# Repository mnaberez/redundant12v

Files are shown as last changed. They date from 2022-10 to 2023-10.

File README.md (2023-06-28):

# Rackmount Redundant 12V Power Supply

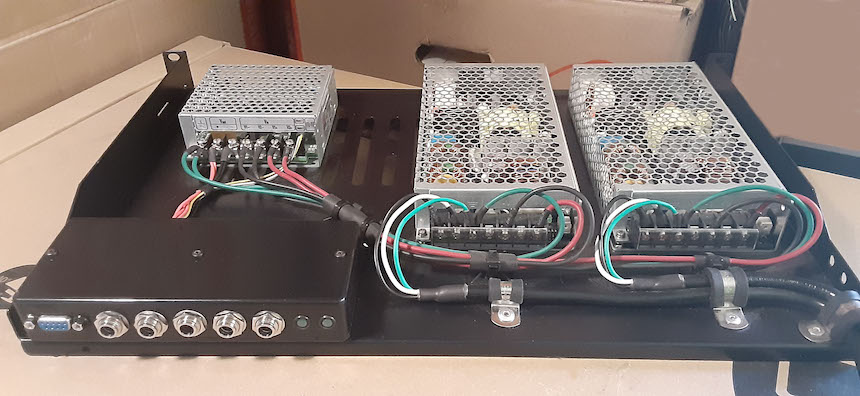
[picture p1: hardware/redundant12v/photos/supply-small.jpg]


This is a redundant, but not hot-swappable, 12VDC power supply.  It has these features:

 - Two AC cords.  Either cord can lose AC power without disrupting the 12VDC output.

 - Five 12VDC output jacks.  Any individual jack can supply ~6A maximum but the supply is only capable of providing ~16A maximum across all jacks.

 - Remote monitoring.  A serial port provides a simple "on/off" status that indicates when one of the two onboard DC supplies loses its AC power or otherwise fails.

It is built on a 1U rack shelf but requires at least 2U because it is slightly taller than 1U.  The extra air space is also needed for cooling because the supply has no fans.

## Background

Rackmount [Automatic Transfer Switches](https://web.archive.org/web/20220408134749/https://www.youtube.com/watch?v=JSWmmY9tKrM) from companies such as [APC](https://web.archive.org/web/20220408135631if_/https://download.schneider-electric.com/files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) and [CyberPower](https://web.archive.org/web/20220408140138if_/https://www.cyberpower.com/tw/en/File/GetCyberpowerFileByDocId/DS-21040002-01) can be used to provide AC power redundancy for devices with a single AC cord.  I wanted redundant power for the single-corded devices in my rack and noticed that they all ran off 12VDC power bricks.  Instead of buying an ATS unit and plugging the bricks into it, I built this redundant 12VDC supply to eliminate the bricks.  It can be built for less than the cost of most ATS units.

## Parts List

| Part | Qty | Notes |
|---|-----|---|
|[Meanwell ERDN40-12 12VDC Redundancy Module](https://www.mouser.com/ProductDetail/709-ERDN40-12) | 1 | [Datasheet](https://web.archive.org/web/20220407021145if_/https://www.meanwell.com/upload/pdf/ERDN40/ERDN40-spec.pdf) |
|[Meanwell MSP-200-12 12VDC 16.7A Power Supply](https://www.mouser.com/ProductDetail/709-MSP200-12) | 2 | [Datasheet](https://web.archive.org/web/20220407021309if_/https://www.mouser.com/datasheet/2/260/MSP_200_SPEC-1109886.pdf).  Selected for built-in protections and no required minimum current. |
|[Pinfox 10' 18 AWG 3 Prong Heavy Duty 120V 10A AC Cord](https://www.amazon.com/gp/product/B07QYRMD6D) | 2 | One AC cord for each MSP-200-12. |
|[Raising Electronics 701401004 19" 1U 12" Deep Rack Shelf](https://www.amazon.com/gp/product/B01M8HKRA7) | 1 | [Product Page](https://web.archive.org/web/20220408132026if_/https://risingracks.com/cantilever-server-shelf-vented-black-shelves-rack-mount-19-1u-12-300mm-deep/) |
|[10pc M3x6mm Plastic Pan Head Screw](https://www.ebay.com/itm/254913074827) | 1 | 10 screws used for mounting the Meanwell units to the shelf.  Plastic ensures no possibility of shorting. |
|[10pc M3x25mm Female-Female Steel Standoff](https://www.ebay.com/itm/113410581076) | 1 | 4 standoffs used inside the project box to mount it to the shelf and secure the lid |
|[25pc M3x8mm Pan Head Screw Steel Black](https://www.ebay.com/itm/111839544046) | 1 | 8 screws used with the 4 project box standoffs (2 screws per standoff) |
|[50pcs M3x6mm Nylon Standoffs with M3x6mm Nylon Screws](https://www.ebay.com/itm/262850128455) | 1 | 4 standoffs and 4 screws used to mount PCB inside project box.  Plastic ensures no possibility of shorting.  Standoffs are epoxied to the project box. |
|[Hammond 1591HSBK Project Box](https://www.digikey.com/en/products/detail/hammond-manufacturing/1591HSBK/130882) | 1 | [Datasheet](https://web.archive.org/web/20210928162934if_/http://www.hammondmfg.com/pdf/1591H.pdf), [Bulletin](https://web.archive.org/web/20220407164638if_/https://www.mouser.com/datasheet/2/177/1591-1389824.pdf) |
|[L-Com SDG400XS D-Sub 50pc Jackscrew/Washer/Nut](https://www.newark.com/l-com/sdg400xs/jack-screw-4-40-10-16mm/dp/63K2685) | 1 | [Datasheet](https://web.archive.org/web/20220827230745if_/https://www.l-com.com/Images/Downloadables/2D/SDG450XS_2D.pdf).  2 jackscrews, 2 lock washers, and 2 hex nuts used to mount DB9 to project box. |
|[5pcs DB9 Female to IDC Panel Mount](https://www.ebay.com/itm/311374355272) | 1 | 1 DB9 connector used to make the DB9-to-PCB cable inside the project box. |
|[10pcs 2x5 pin IDC Female](https://www.ebay.com/itm/323745402692) | 1 | 1 IDC connector used to make the DB9-to-PCB cable inside the project box.  The top of the strain relief must be shaved down a bit to fit in the box. |
|[Ribbon Cable 14 conductor 6' long](https://www.ebay.com/itm/282211468932) | 1 | Cut down to 10 conductors and 6" long, used to make the DB9-to-PCB cable inside the project box. |
|[DB9 Male/Female 5' Cable](https://www.mouser.com/ProductDetail/523-CS-DSDMDB09MF005) | 1 | [Datasheet](https://web.archive.org/web/20220719155819if_/https://www.mouser.com/datasheet/2/18/1/CS_DSDMDB09MF-2079775.pdf).  For direct connection between the box and a PC with a DB9 serial port. |
|[FTDI-US232R-100 1m USB-Serial Cable](https://www.mouser.com/ProductDetail/895-US232R-100-BLK) | 1 | [Datasheet](https://web.archive.org/web/20220828230546if_/https://www.mouser.com/datasheet/2/163/DS_US232R-10_R-100-500-1669828.pdf).  For connecting to a PC without a DB9 serial port, use this adapter together with the above DB9 cable. |
|[Lumex SSI-LXH387GD Panel Mount Green LED](https://www.mouser.com/ProductDetail/696-SSI-LXH387GD) | 2 | [Datasheet](https://web.archive.org/web/20221002231549if_/https://www.mouser.com/datasheet/2/244/LUMX_S_A0001762456_1-2551886.pdf).  Mounted on project box to show the "on" status of each power supply.
|[Switchcraft L712ASH 2.5mm Locking Barrel Socket](https://www.mouser.com/ProductDetail/502-L712ASH) | 5 | [Datasheet](https://web.archive.org/web/20220407035419if_/https://www.mouser.com/datasheet/2/393/L712ASH-L722ASH_CD-1110860.pdf), [Bulletin](https://web.archive.org/web/20220407164041if_/https://www.switchcraft.com/Documents/switchcraft_npb_637_high_temp_jacks_plugs.pdf).  Mounted on project box for DC outputs. |
|[Switchcraft 761KSH15 2.5mm Locking Barrel Plug](https://www.mouser.com/ProductDetail/502-761KSH15) | 5 | [Datasheet](https://web.archive.org/web/20220407035117if_/https://www.mouser.com/datasheet/2/393/761KSH-S761KSH_CD-1110850.pdf). See bulletin above for electrical info.  For building DC cables out to devices. |
|[14 AWG GXL Wire 10' Long](https://www.ebay.com/itm/293094627307) | 3 | 1 each: red, green, black.  Cut to length for high current DC wiring |
|[1200Pcs Assorted Crimp Terminals](https://www.ebay.com/itm/172856488315) | 1 | 21 M4 size ring connectors used with terminal blocks on Meanwell units |
|[DC Extension Cable 18 AWG 12VDC 10A 33' Long](https://www.ebay.com/itm/133233779533) | 1 | Connectors cut off and discarded; used to make output cables and for wiring inside Project Box |
|[10pc Dupont 2x2 Female Housing](https://www.ebay.com/itm/141510327734) | 1 | 1 housing used to make ERDN40 alarm cable |
|[10pc Dupont 2-pin 26AWG Female-Female Jumper Cable](https://www.ebay.com/itm/254959908608) | 1 | 2 cables used to make ERDN40 alarm cable |
|[Molex KK 22-01-3077 7-pin Housing](https://www.mouser.com/ProductDetail/538-22-01-3077)| 1 | 1 housing used for PCB connector |
|[125pc Rubber Grommet Set](https://www.ebay.com/itm/221291687081) | 1 | 1 grommet used around wiring from ERDN40 into project box |
|[TICONN 80pc Stainless Steel Hose Clamp Set](https://www.amazon.com/gp/product/B094YP2F3D) | 1 | 3 hose clamps used for AC cord strain relief |
|[100pc 1/4" Aluminum Pop Rivet Set](https://www.harborfreight.com/100-piece-1-4-quarter-inch-aluminum-blind-rivet-set-67619.html) | 1 | 3 pop rivets used to secure hose clamps to shelf |
|[6pc Phoenix Contact Cable Tie Mount Base](https://www.mouser.com/ProductDetail/651-3240709) | 1 | 3 bases used for cable management |
|[Panduit Cable Tie Assortment](https://www.mouser.com/ProductDetail/644-KB-550) | 1 | 3 ties used for cable management |
|[42pc Marine Heat Shrink Tubing](https://www.harborfreight.com/42-piece-marine-heat-shrink-tubing-67598.html) | 1 | For insulating cable ends and also cable management |

## PCB Components

| Part | Qty | Reference Designators |
|---|-----|---|
|[ATTINY212-SSF](https://www.mouser.com/ProductDetail/579-ATTINY212-SSF) Microcontroller SOIC-8 | 1 | U1 |
|[MAX232EID](https://www.mouser.com/ProductDetail/595-MAX232EID) TI RS232 Transceiver SOIC-8 | 1 | U2 |
|[ECS-3951M-018-AU-TR](https://www.mouser.com/ProductDetail/520-3951M-018-AU) Oscillator 1.8432 MHz | 1 | X1 |
|[BZX84-A15,215](https://www.mouser.com/ProductDetail/771-BZX84-A15,215) Zener Diode 15V | 1 | D1 |
|[F1206B1R00FSTR](https://www.mouser.com/ProductDetail/581-F1206B1R00FSTR) Fuse 1206 | 1 | F1 |
|[08055C104J4T2A](https://www.mouser.com/ProductDetail/581-08055C104J4T2A) Capacitor 0.1uF 50V 0805 | 4 | C1, C2, C4, C8 |
|[08053C105K4Z4A](https://www.mouser.com/ProductDetail/581-08053C105K4Z4A) Capacitor 1uF 25V 0805 | 4 | C3, C5, C6, C7 |
|[CGA4J1X7S1E106K125AC](https://www.mouser.com/ProductDetail/810-CGA4J1X7S1E106K1) Capacitor 10uF 25V 0805 | 1 | C9 |
|[RK73H2ARTTD4702F](https://www.mouser.com/ProductDetail/660-RK73H2ARTTD4702F) Resistor 47K 0805 | 2 | R1, R2 |
|[ERJ-P06F2000V](https://www.mouser.com/ProductDetail/667-ERJ-P06F2000V) Resistor 200ohm  0805 | 2 | R3, R4 |
|[22-12-2074](https://www.mouser.com/ProductDetail/538-22-12-2074) Molex KK 7-pin Right Angle | 1 | J1 |
|[IDC 2x5 Header](https://www.ebay.com/itm/254517739367) Shrouded Through Hole | 1 | J2 |

## Author

[Mike Naberezny](https://github.com/mnaberez)

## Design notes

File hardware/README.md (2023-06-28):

# Hardware

The redundant power supply is mostly wired by hand but a printed circuit board with a microcontroller is used to report the status to a PC.  The board was designed using KiCad.  The [schematic](./redundant12v/schematic.pdf) and [Gerber files](./redundant12v/gerbers.zip) are the final version.  See [`firmware/`](../firmware) for how to program the microcontroller.

## Photos



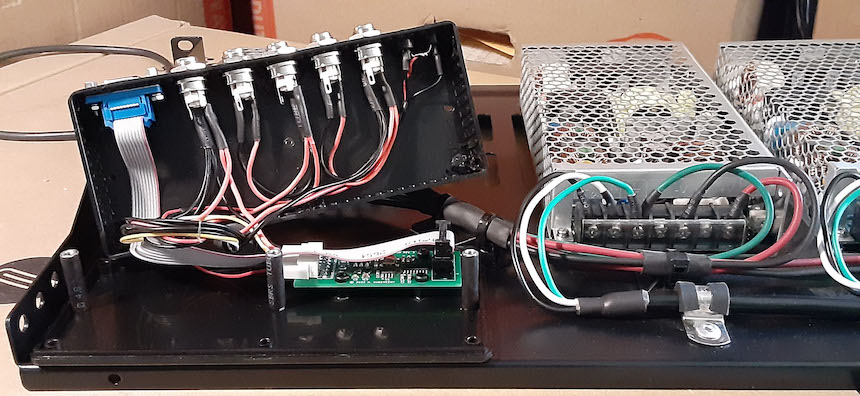
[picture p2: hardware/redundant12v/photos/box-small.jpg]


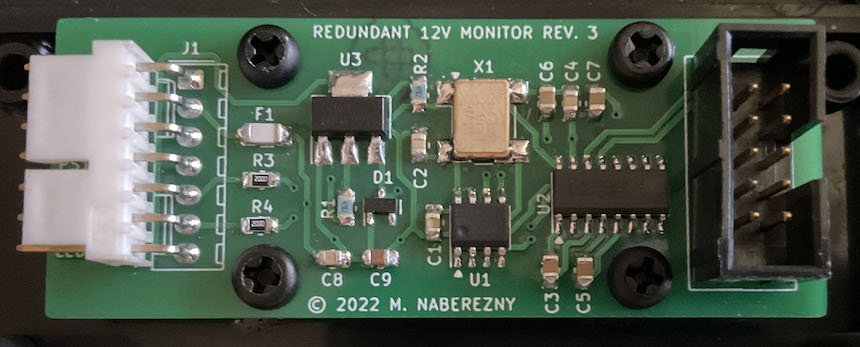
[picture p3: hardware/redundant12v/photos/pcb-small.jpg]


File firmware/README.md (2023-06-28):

# Firmware

The firmware runs on an [Attiny212 or Attiny412](https://web.archive.org/web/20220715022600if_/https://ww1.microchip.com/downloads/aemDocuments/documents/MCU08/ProductDocuments/DataSheets/ATtiny212-14-412-14-Automo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).  It configures the UART for 9600-N81 and then waits for a carriage return (`\r`).  Anything else is ignored.  When a `\r` is received, a status line ending with `\r\n` is printed:

```
PS0=OK,PS1=FAIL
```

Each supply is shown as either `OK` or `FAIL`.  

Note that while the firmware has the ability to report a simultaneous failure of both supplies, this won't work in practice, because the MCU itself will lose power.  If the MCU does not respond, it indicates a failure of both supplies or a failure of the MCU.  

## Design

The firmware consists of less than 500 bytes of AVR assembly.  Since the MCU is installed in an enclosure with no way to power it off or reset it, and will hopefully run for years, the firmware has been designed to be as simple and resilient as possible.  

There is a main loop that continuously polls the UART.  If a `\r` is received, the two digital inputs are read and the status line is sent.  Otherwise, RAM and ROM tests are performed before the next poll.  The intent of this is to use the idle time to try and detect hardware problems that could cause a false status to be reported.  The ROM test is done by the CRCSCAN peripheral, which is also configured to run on reset and block the firmware from starting if the CRC check fails.  If the firmware encounters any error while it runs, it resets the MCU using the RSTCTRL peripheral.  No interrupts are used so execution is more deterministic.  If the program counter somehow wanders into the interrupt vectors or the unused code space, the firmware will reset the MCU.  The watchdog peripheral is also configured to reset the MCU if the firmware gets stuck somehow.  

The two status LEDs on the enclosure are not controlled by the MCU, so they will continue to reflect the state of the supplies if the MCU fails.

## Build

Building requires:

- ASAVR (part of the [ASxxxx](https://shop-pdp.net/ashtml/) cross-assemblers package)
- [SRecord](http://srecord.sourceforge.net/) version 1.64 or later
- GNU [Make](https://www.gnu.org/software/make/)
- A Unix-like operating system (e.g. Linux, macOS)

Run `make` to build the firmware for the Attiny212.  It will produce two files in Intel hex format: one for the Attiny212 flash and one for the fuses.  See the [`Makefile`](./Makefile) and the [GitHub workflow](../.github/workflows/main.yml).

To build for the Attiny412 instead, run `make MCU=t412`.  There's no benefit to using the Attiny412 over the Attiny212 for this project.  Use whichever one has better pricing or availability.

## Flash

Flashing requires:

- [AVRDUDE](https://github.com/avrdudes/avrdude)
- An [Atmel-ICE](https://www.microchip.com/en-us/development-tool/ATATMEL-ICE) device programmer

Run `make program` to flash the MCU.  This will completely program a blank part so that it is ready to use.

The [Adafruit SWD Breakout Board](https://www.adafruit.com/product/2743) can be used to connect the Atmel-ICE to the test points on the bottom of the PCB.  The ribbon cable plugs into the "AVR" port on the Atmel-ICE.  The connections from the breakout board to the test points are: GNDd → GND, KEY → VTG, NC → UPDI.  See this [photo of the connections](../hardware/redundant12v/photos/updi.jpg).

## Test

[Minicom](https://salsa.debian.org/minicom-team/minicom/) can be used to test:

```text
$ minicom -b 9600 -D /dev/ttyS0
```

The status line should be displayed when the enter key is pressed.

## References

- [Attiny212 / Attiny412 Datasheet](https://web.archive.org/web/20220715022600if_/https://ww1.microchip.com/downloads/aemDocuments/documents/MCU08/ProductDocuments/DataSheets/ATtiny212-14-412-14-Automo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)
- [AVR Instruction Set Manual](https://web.archive.org/web/20211122051203if_/http://ww1.microchip.com/downloads/en/devicedoc/atmel-0856-avr-instruction-set-manual.pdf)

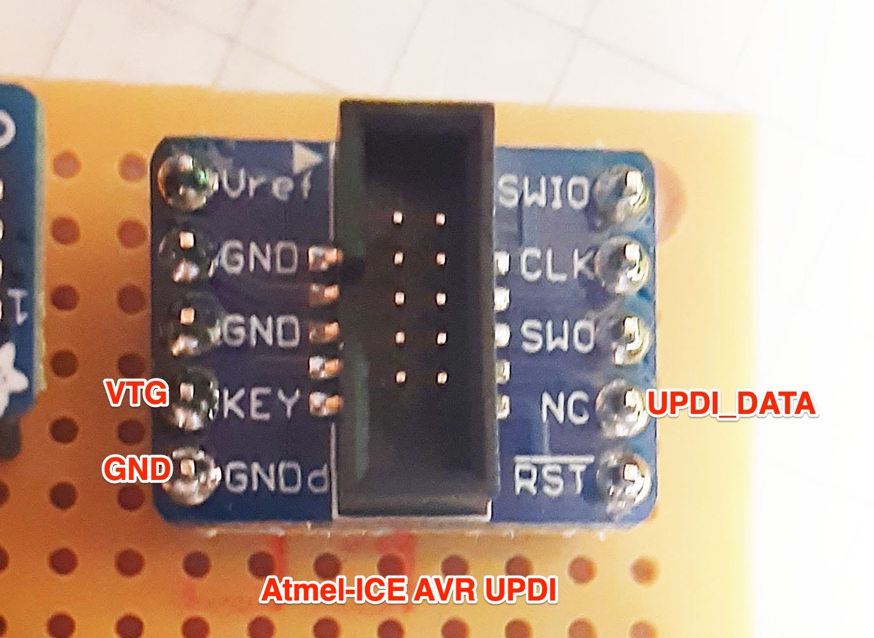
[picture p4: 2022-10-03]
hardware/redundant12v/photos/updi.jpg

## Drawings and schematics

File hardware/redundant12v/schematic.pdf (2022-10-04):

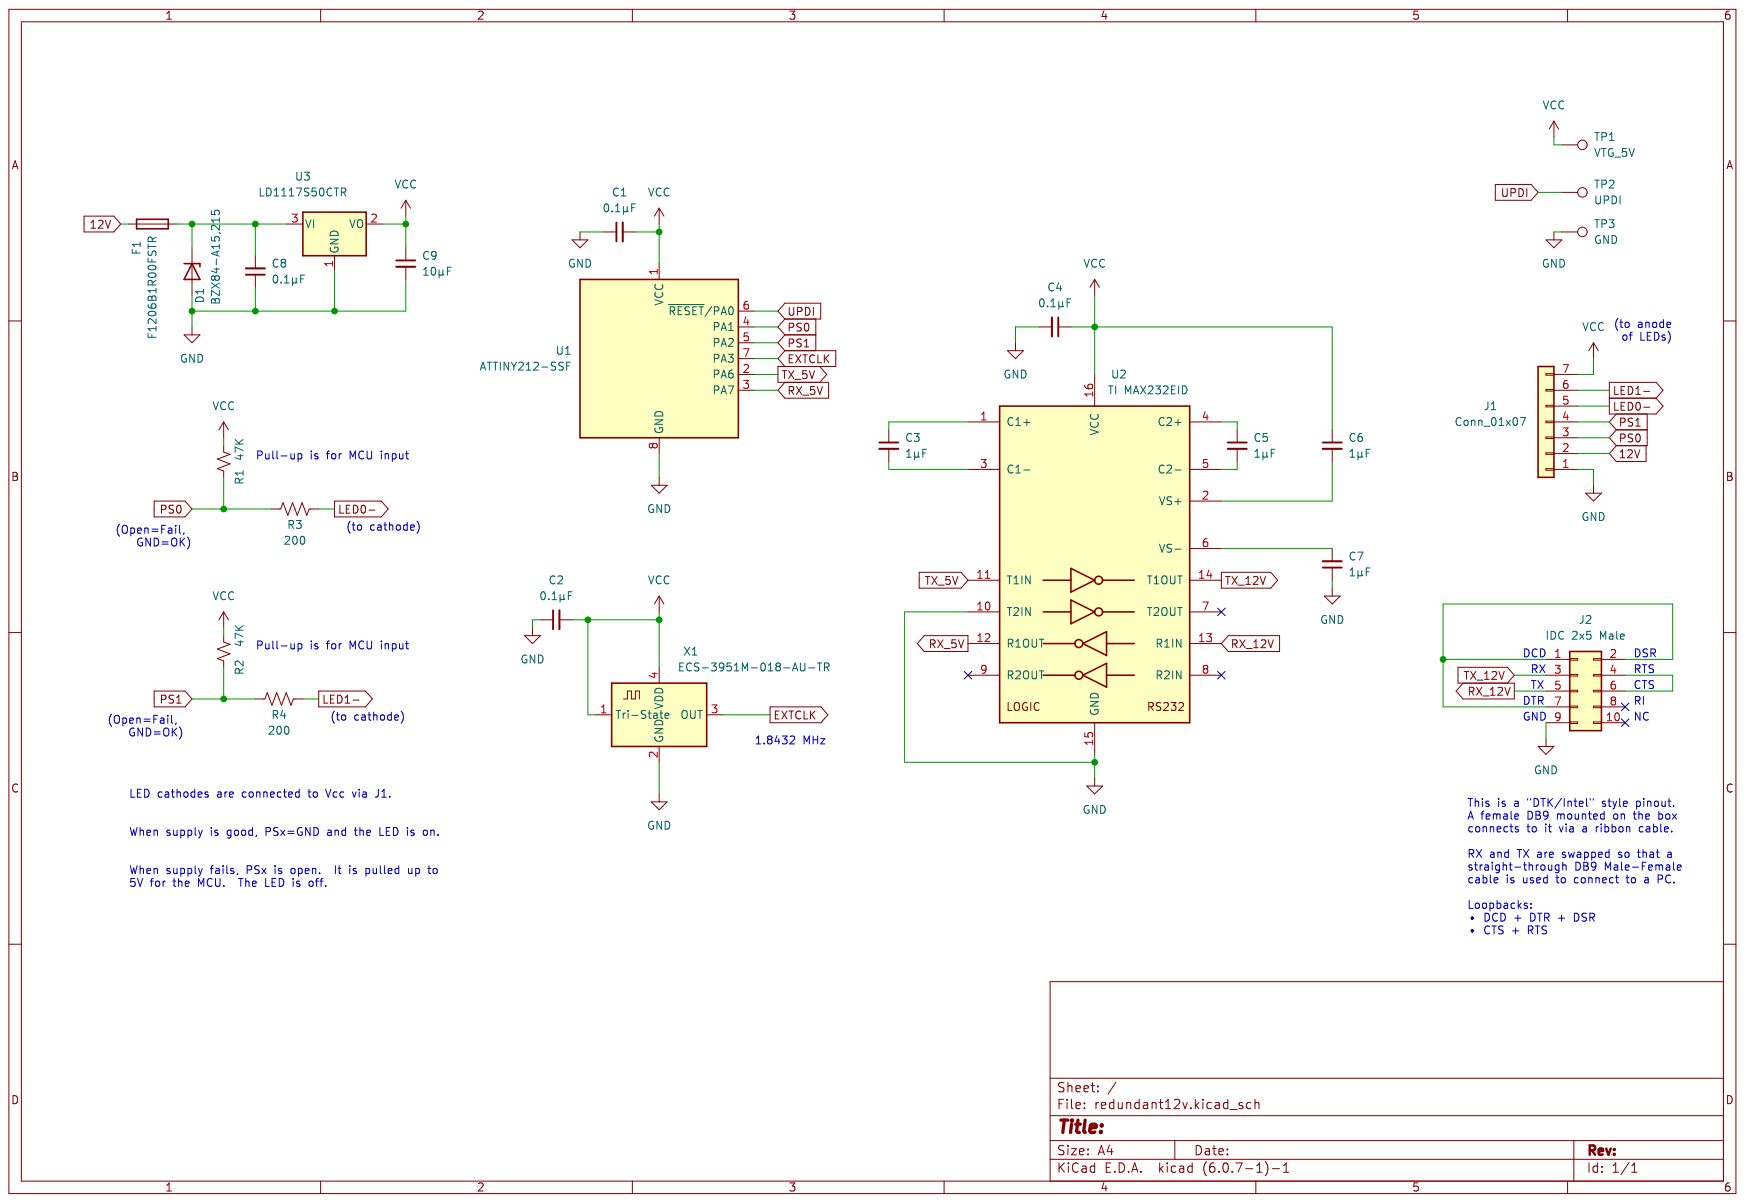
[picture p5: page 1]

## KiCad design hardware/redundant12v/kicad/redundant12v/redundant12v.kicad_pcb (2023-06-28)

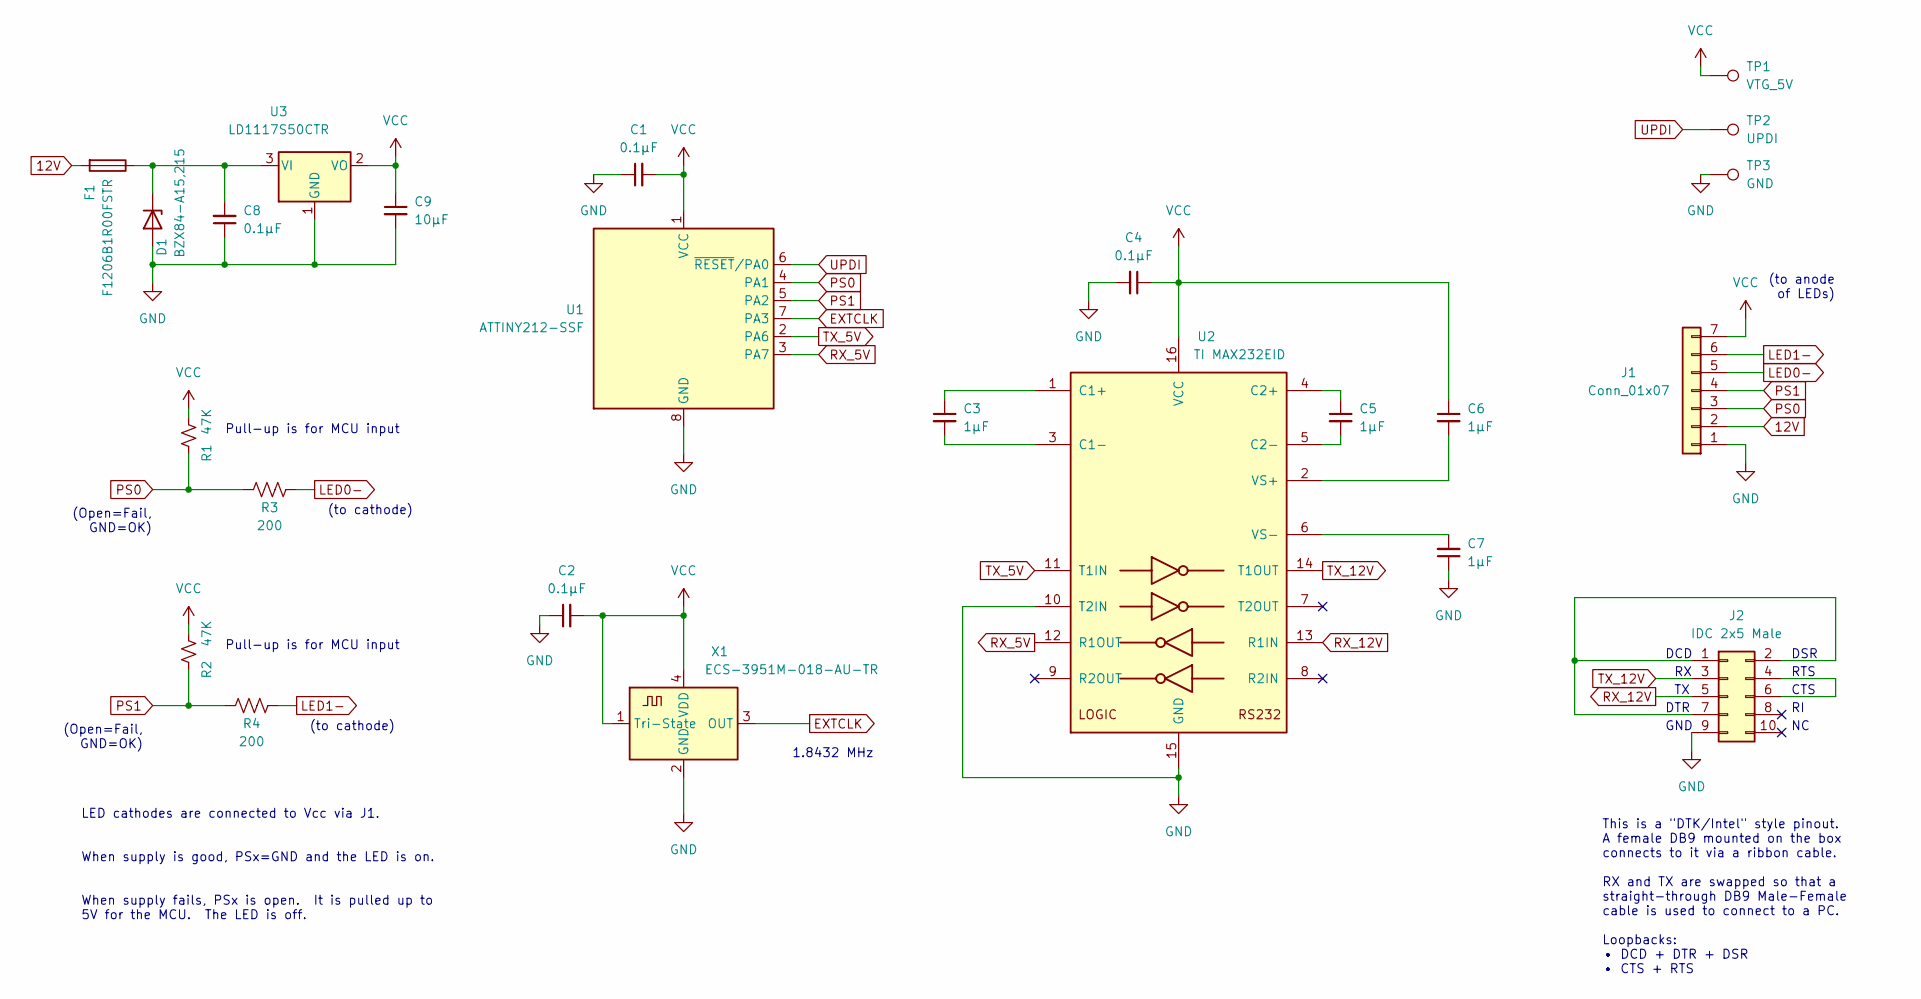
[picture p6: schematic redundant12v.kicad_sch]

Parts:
C1, C2, C4, C8: 0.1μF; C_0805_2012Metric_Pad1.18x1.45mm_HandSolder
C3, C5, C6, C7: 1μF; C_0805_2012Metric_Pad1.18x1.45mm_HandSolder
C9: 10μF; C_0805_2012Metric_Pad1.18x1.45mm_HandSolder
D1: BZX84-A15,215; SOT-23
F1: F1206B1R00FSTR; Fuse_1206_3216Metric_Pad1.42x1.75mm_HandSolder
J1: Conn_01x07; Molex_KK-254_AE-6410-07A_1x07_P2.54mm_Vertical
J2: IDC 2x5 Male; IDC-Header_2x05_P2.54mm_Vertical
R1, R2: 47K; R_0805_2012Metric_Pad1.20x1.40mm_HandSolder
R3, R4: 200; R_0805_2012Metric_Pad1.20x1.40mm_HandSolder
TP1: VTG_5V; TestPoint_Pad_D2.5mm
TP2: UPDI; TestPoint_Pad_D2.5mm
TP3: GND; TestPoint_Pad_D2.5mm
U1: ATTINY212-SSF; SOIC-8_3.9x4.9mm_P1.27mm
U2: TI MAX232EID; SOIC-16_3.9x9.9mm_P1.27mm
U3: LD1117S50CTR; SOT-223-3_TabPin2
X1: ECS-3951M-018-AU-TR; Oscillator_SMD_Abracon_ASV-4Pin_7.0x5.1mm_HandSoldering

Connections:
12V: F1.2, J1.2
EXTCLK: U1.7 (PA3), X1.3 (OUT)
GND: C1.1, C2.1, C4.2, C7.1, C8.1, C9.2, D1.1 (A), J1.1, J2.9, TP3.1, U1.8 (GND), U2.10 (T2IN), U2.15 (GND), U3.1 (GND), X1.2 (GND)
LED0-: J1.5, R3.2
LED1-: J1.6, R4.2
unnamed: C3.1, U2.1 (C1+)
unnamed: C3.2, U2.3 (C1-)
unnamed: C5.1, U2.4 (C2+)
unnamed: C5.2, U2.5 (C2-)
unnamed: C6.2, U2.2 (VS+)
unnamed: C7.2, U2.6 (VS-)
unnamed: C8.2, D1.3 (K), F1.1, U3.3 (VI)
unnamed: J2.1, J2.2, J2.7
unnamed: J2.4, J2.6
PS0: J1.3, R1.2, R3.1, U1.4 (PA1)
PS1: J1.4, R2.2, R4.1, U1.5 (PA2)
RX_5V: U1.3 (PA7), U2.12 (R1OUT)
RX_12V: J2.5, U2.13 (R1IN)
TX_5V: U1.2 (PA6), U2.11 (T1IN)
TX_12V: J2.3, U2.14 (T1OUT)
UPDI: TP2.1, U1.6 (~RESET/PA0)
VCC: C1.2, C2.2, C4.1, C6.1, C9.1, J1.7, R1.1, R2.1, TP1.1, U1.1 (VCC), U2.16 (VCC), U3.2 (VO), X1.1 (Tri-State), X1.4 (VDD)

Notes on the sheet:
RTS
1.8432 MHz
DTR
(to anode of LEDs)
DCD
(to cathode)
(Open=Fail, GND=OK)
LED cathodes are connected to Vcc via J1. When supply is good, PSx=GND and the LED is on. When supply fails, PSx is open. It is pulled up to 5V for the MCU. The LED is off.
This is a "DTK/Intel" style pinout. A female DB9 mounted on the box connects to it via a ribbon cable. RX and TX are swapped so that a straight-through DB9 Male-Female cable is used to connect to a PC. Loopbacks: • DCD + DTR + DSR • CTS + RTS
DSR
CTS
Pull-up is for MCU input
GND

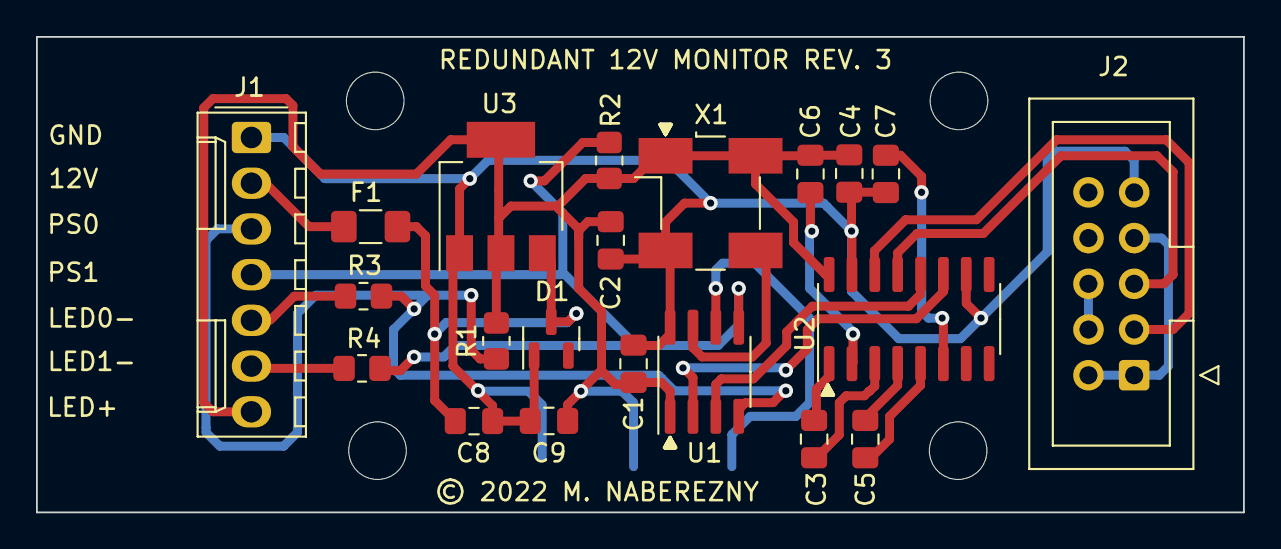
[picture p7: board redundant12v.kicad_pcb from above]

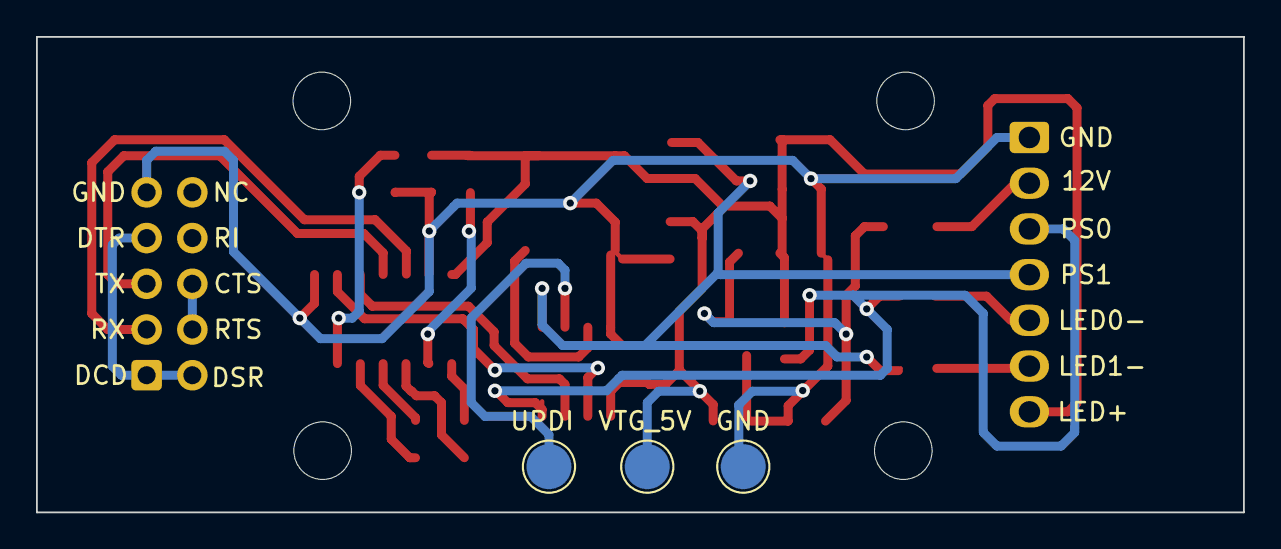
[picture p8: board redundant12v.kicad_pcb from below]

Board: 2 copper layers, 67.1 x 26.4 mm, 24 parts (3 on the bottom side), 22 nets.

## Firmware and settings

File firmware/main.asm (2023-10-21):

;ATtiny212 or ATtiny412
;1 VCC
;2 PA6 TX to MAX232
;3 PA7 RX from MAX232
;4 PA1 Digital Input: Power Supply 0 failed (0=ok, 1=failed)
;5 PA2 Digital Input: Power Supply 1 failed (0=ok, 1=failed)
;6 UPDI
;7 EXTCLK (from 1.8432 MHz oscillator)
;8 GND

    ;Definitions file "tn212def.asm" or "tn412def.asm"
    ;will be included first by the Makefile.

    .area code (abs)
    .list (me)

    .org PROGMEM_START/2  ;/2 because PROGMEM_START constant is byte-addressed
                          ;but ASAVR treats program space as word-addressed.
    rjmp reset

    ;All interrupt vectors jump to fatal error (interrupts are not used)
    .rept INT_VECTORS_SIZE - 1
    rjmp fatal
    .endm

    ;Code starts at first location after vectors
    .assume . - ((PROGMEM_START/2) + INT_VECTORS_SIZE)

reset:
    ;Clear RAM
    ldi ZL, <INTERNAL_SRAM_START
    ldi ZH, >INTERNAL_SRAM_START
    clr r16
1$: st Z, r16                 ;Store 0 at Z
    ld r16, Z+                ;Read it back, increment Z
    tst r16                   ;Did it read back as 0?
    breq 2$                   ;Yes: continue clearing
    rjmp fatal                ;No: hardware failure, jump to fatal
2$: cpi ZL, <(INTERNAL_SRAM_END+1)
    brne 1$
    cpi ZH, >(INTERNAL_SRAM_END+1)
    brne 1$

    ;Initialize stack pointer
    ldi r16, <INTERNAL_SRAM_END
    out CPU_SPL, r16
    ldi r16, >INTERNAL_SRAM_END
    out CPU_SPH, r16

    rcall wdog_init
    rcall osci_init
    rcall gpio_init
    rcall uart_init

main_loop:
    wdr                       ;Keep watchdog happy

    rcall self_test           ;Self-test each iteration (jumps to fatal if failed)

    rcall uart_has_error      ;UART error occurred?
    brcc 1$                   ;No: keep going
    rjmp fatal                ;Yes: reset to ensure UART fully recovers

1$: rcall uart_has_byte       ;Byte received?
    brcc main_loop            ;No: keep waiting

    rcall uart_read_byte
    cpi r16, '\r              ;Byte received = '\r'?
    brne main_loop            ;No: keep waiting

    rcall check_supplies
    rcall send_status_line
    rjmp main_loop

;Check power supplies 0 and 1
;Blocks for at least 25ms to debounce
;Returns R16 = Bitfield of power supply failed statuses
;              Bit 7..2 Unused
;              Bit    1 Power Supply 1 failed (0=ok, 1=failed)
;              Bit    0 Power Supply 0 failed (0=ok, 1=failed)
;Destroys R16,R17,R18
check_supplies:
    ldi r18, 25             ;Debounce: PORTA must be the same for N readings

1$: lds r16, PORTA_IN       ;Read once
    andi r16, 0b00000110    ;PA2=Power Supply 1, PA1=Power Supply 0

    push r16
    rcall delay_1ms         ;Delay 1ms
    pop r16

    lds r17, PORTA_IN       ;Read again
    andi r17, 0b00000110

    cp r16, r17
    brne check_supplies     ;Start over if readings are different

    dec r18
    brne 1$                 ;Loop until all required readings are the same

    ;R16 and R17 both contain the debounced and masked PORTA
    lsr r16                 ;Rotate right once so bit 1 = Supply 1, bit 0 = Supply 0
    ret

;Send status line like "PS0=OK,PS1=OK\r\n"
;Call with R16=statuses bitfield from check_supplies
send_status_line:
    push r16                ;Push supply statuses bitfield
    andi r16, 1             ;Mask off to leave only bit 0 (supply 0 status)
    ldi r17, '0             ;Supply number to display in ASCII = '0'
    rcall send_ps_status

    ldi r16, ',
    rcall uart_send_byte

    pop r16                 ;Pop supplies bitfield
    lsr r16                 ;Rotate bit 1 (supply 1 status) into bit 0
    ldi r17, '1             ;Supply number to display in ASCII = '1'
    rcall send_ps_status

    rjmp uart_send_crlf

;Send "PSn=OK" or "PSn=FAIL"
;Call with R16=failed status in bit 0 (0=ok, 1=failed)
;          R17=power supply number in ASCII ('0' or '1')
send_ps_status:
    push r16              ;Push status in bit 0
    push r17              ;Push power supply number

    ldi ZL, <(ps * 2)
    ldi ZH, >(ps * 2)
    rcall uart_send_str   ;Send "PS"

    pop r16               ;Pop power supply number in ASCII
    rcall uart_send_byte

    pop r16               ;Pop status in bit 0
    sbrc r16, 0           ;Skip branch if bit 0 is clear (clear = supply is ok)
    breq 1$               ;Branch to show failed

    ldi ZL, <(equals_ok * 2)
    ldi ZH, >(equals_ok * 2)
    rjmp uart_send_str    ;Send "=OK"

1$: ldi ZL, <(equals_fail * 2)
    ldi ZH, >(equals_fail * 2)
    rjmp uart_send_str    ;Send "=FAIL"

.nval ps,.
    .ascii "PS"
    .byte 0

.nval equals_fail,.
    .ascii "=FAIL"
    .byte 0

.nval equals_ok,.
    .ascii "=OK"
    .byte 0

;Ensure the watchdog was started by the fuses and reset the timer.
;The WDR instruction must be executed at least once every 4 seconds
;or the watchdog will reset the system.
wdog_init:
    ;Ensure watchdog period has been configured
    lds r16, WDT_CTRLA
    andi r16, WDT_PERIOD_gm
    cpi r16, WDT_PERIOD_4KCLK_gc      ;Watchdog period set by the fuses?
    breq 1$                           ;Yes: continue
    rjmp fatal                        ;No: bad fuses, jump to fatal

    ;Ensure watchdog is locked so it can't be stopped
1$: lds r16, WDT_STATUS
    sbrs r16, WDT_LOCK_bp             ;Skip fatal if locked
    rjmp fatal

    wdr                               ;Reset watchdog timer
    ret

;Switch to the external oscillator.
;Interrupts must be disabled before calling.
osci_init:
    ldi r16, CPU_CCP_IOREG_gc

    ;Disable clock prescaler
    clr r17                           ;No prescaler
    out CPU_CCP, r16                  ;Unlock Protected I/O Registers
    sts CLKCTRL_MCLKCTRLB, r17        ;Disable clock prescaler

    ;Switch to external 1.8432 MHz oscillator
    ldi r17, CLKCTRL_CLKSEL_EXTCLK_gc ;EXTCLK 1.8432 MHz external clock
    out CPU_CCP, r16                  ;Unlock Protected I/O Registers
    sts CLKCTRL_MCLKCTRLA, r17        ;Use EXTCLK for main clock
    ret

;Set up GPIO directions (UART pin directions are set in uart_init)
gpio_init:
    ldi r16, 1<<2 | 1<<1    ;PA2, PA1 = input
    sts PORTA_DIRCLR, r16
    ret

;Initialize the UART
uart_init:
    ;Set baud rate to 9600 bps for 1.8432 MHz crystal
    ;#define F_CPU 1843200
    ;#define USART0_BAUD_RATE(BAUD_RATE) ((float)(F_CPU * 64 / (16 * (float)BAUD_RATE)) + 0.5)
    ;USART0.BAUD = (uint16_t)USART0_BAUD_RATE(9600);
    ldi r16, 0x00
    sts USART0_BAUDL, r16
    ldi r16, 0x03
    sts USART0_BAUDH, r16

    ;8N1
    ldi r16, USART_NORMAL_CMODE_ASYNCHRONOUS_gc | USART_NORMAL_CHSIZE_8BIT_gc | USART_NORMAL_PMODE_DISABLED_gc | USART_NORMAL_SBMODE_1BIT_gc
    sts USART0_CTRLC, r16

    ;Set pin directions
    ldi r16, 1<<7           ;pa7 = rx (input)
    sts PORTA_DIRCLR, r16
    ldi r16, 1<<6           ;pa6 = tx (output)
    sts PORTA_DIRSET, r16

    ;Enable transmit and receive
    lds r16, USART0_CTRLB
    ori r16, USART_TXEN_bm | USART_RXEN_bm
    sts USART0_CTRLB, r16
    ret

;Check if one of the UART error flags is set
;Sets carry on error
uart_has_error:
    clc
    lds r16, USART0_RXDATAH
    andi r16, USART_BUFOVF_bm | USART_FERR_bm | USART_PERR_bm
    breq 1$
    sec
1$: ret

;Check if a byte has been received from the UART
;Sets carry if one is available
uart_has_byte:
    lds r16, USART0_STATUS
    .assume 7 - USART_RXCIF_bp  ;RXCIF must be bit 7 for ROL to work
    rol r16                     ;Rotate RXCIF into carry (0=no char, 1=char avail)
    ret

;Read a byte from the UART
;Blocks until a byte has been received
uart_read_byte:
    rcall uart_has_byte
    brcc uart_read_byte
    lds r16, USART0_RXDATAL
    ret

;Write a byte to the UART
;Blocks until the UART accepts the byte
;Destroys R17
uart_send_byte:
    lds r17, USART0_STATUS
    sbrs r17, USART_DREIF_bp  ;Skip next if USART_DREIF=1 (tx ready)
    rjmp uart_send_byte

    sts USART0_TXDATAL, r16
    ret

;Send CRLF to the UART.
;Destroys R16
uart_send_crlf:
    ldi r16, '\r
    rcall uart_send_byte
    ldi r16, '\n
    rjmp uart_send_byte

;Send a null-terminated string to the UART
;Destroys R16 and Z
uart_send_str:
    lpm r16, Z+           ;Read byte from string
    tst r16               ;End of string?
    breq 2$               ;Yes: Branch to return
    rcall uart_send_byte
    rjmp uart_send_str
2$: ret

;Wait 1ms.  Destroy R16,R17
delay_1ms:
    ldi r16, 6
1$: ldi r17, 0xc5
2$: dec r17
    brne 2$
    dec r16
    brne 1$
    ret

;Perform self-test.  Jumps to fatal if the test fails.
self_test:
    rcall test_ram
    rjmp test_rom

;Test the RAM non-destructively.  Jumps to fatal if test the fails.
;Interrupts must be disabled before calling.
;Destroys R20, R21, Z.
test_ram:
    ldi ZL, <INTERNAL_SRAM_START
    ldi ZH, >INTERNAL_SRAM_START

1$: ld r21, Z       ;Save original value in R21

    ldi r20, 0x55
    st Z, r20
    ld r20, Z
    cpi r20, 0x55
    breq 2$
    rjmp fatal      ;Pattern 0x55 failed

2$: ldi r20, 0xaa
    st Z, r20
    ld r20, Z
    cpi r20, 0xaa
    breq 3$
    rjmp fatal      ;Pattern 0xAA failed

3$: st Z+, r21      ;Restore original value, increment Z
    cpi ZL, <(INTERNAL_SRAM_END+1)  ;Keep going until all RAM is tested
    brne 1$
    cpi ZH, >(INTERNAL_SRAM_END+1)
    brne 1$

    ret             ;RAM test passed

;Test the flash ROM by using the CRCSCAN peripheral to compute the
;CRC16 of the flash and compare it to the CRC16 stored in the last
;two bytes of the flash.  Jumps to fatal if they do not match.
;Destroys R16.
test_rom:
    ldi r16, CRCSCAN_ENABLE_bm
    sts CRCSCAN_CTRLA, r16    ;Start CRC scan

1$: lds r16, CRCSCAN_STATUS
    sbrc r16, CRCSCAN_BUSY_bp ;Skip next if busy=0 (scan finished)
    rjmp 1$

    sbrs r16, CRCSCAN_OK_bp   ;Skip next if ok=1 (scan passed)
    rjmp fatal

    ret

;End of code

    ;Fill all unused program words with a nop sled that ends with
    ;a software reset in case the program counter somehow gets here.
    .nval filler_start,.
    .rept ((PROGMEM_END/2) - filler_start - fatal_size)
    nop
    .endm

;Fatal error causes software reset
fatal:
    cli                       ;Disable interrupts
    ldi r16, CPU_CCP_IOREG_gc
    ldi r17, RSTCTRL_SWRE_bm
    out CPU_CCP, r16          ;Unlock Protected I/O Registers
    sts RSTCTRL_SWRR, r17     ;Software Reset

fatal_size = . - fatal

;Last program word (last 2 bytes) will be the CRC16 added by the Makefile
crc16:
    .assume . - (PROGMEM_END/2)

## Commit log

2022-04-10 Add Dupot connectors to parts list
2022-06-28 Add M3 standoffs
2022-06-30 Add screws used with standoffs
2022-07-04 Read power supply status pins
2022-07-05 Invert polarity of power supply input pins
    [main.asm]
2022-07-05 Ignore KiCad temporary files
2022-07-05 Start schematic in KiCad
    [redundant12v.kicad_pcb, redundant12v.kicad_sch]
2022-07-08 Add UART error handling
    [main.asm]
2022-07-10 Add print string routine
2022-07-11 Remove debug code that prints a number in hex out the UART
2022-07-12 Clear RAM on reset and add RAM test
    [main.asm]
2022-07-12 Remove leftovers from UART app note
2022-07-13 Fill unused space with a NOP seld to reset
    [main.asm]
2022-07-13 Fatal error causes programmed reset
    [main.asm]
2022-07-13 Programmed reset on UART error
    [main.asm]
2022-07-14 Add watchdog to reset every 4 seconds
    [main.asm]
2022-07-14 Add fuse programming
2022-07-15 Start watchdog in fuses
2022-07-18 Add regulator circuit and LED drivers
    [redundant12v.kicad_pcb, redundant12v.kicad_sch]
2022-07-18 Reorganize schematic, fix LED polarity
    [redundant12v.kicad_pcb, redundant12v.kicad_sch]
2022-07-19 Add serial port connections
    [redundant12v.kicad_pcb, redundant12v.kicad_sch]
2022-08-20 PCB is mostly routed
    [redundant12v.kicad_pcb, redundant12v.kicad_sch]
2022-08-21 PCB rev 1 finished
    [redundant12v.kicad_pcb, redundant12v.kicad_sch]
2022-08-23 Add values to components on schematic
    [redundant12v.kicad_sch]
2022-08-23 Add PCB components list
2022-08-27 Replace Maxim MAX232ECWE+T with TI MAX232EID for narrower SOIC-16
    [redundant12v.kicad_pcb, redundant12v.kicad_sch]
2022-08-27 Use L-Com SDG400XS jackscrew for mounting DB9
2022-08-27 Fix Mouser links to PCB components
2022-08-29 Add optional FTDI cable part number
2022-08-30 Add link to Hammond case mechanical drawing
2022-08-30 Add front panel drill template
    [drill_template.kicad_pcb]
2022-09-04 Add DB9 cutout to drill template
    [drill_template.kicad_pcb]
2022-09-06 Fix alarm detection, rotate serial connector
    [redundant12v.kicad_pcb, redundant12v.kicad_sch]
2022-09-06 Update parts list for PCB rev 2
2022-09-19 Fix swapped anode and cathode labels
    [redundant12v.kicad_sch]
2022-09-20 Invert status logic for Rev 2 circuit change
    [main.asm]
2022-09-22 Increase width of all traces, widen board under Molex connector
    [redundant12v.kicad_pcb]
2022-10-02 Add standoffs and screws for PCB mounting
2022-10-02 Add panel mount LEDs
2022-10-02 Resistors R1, R2 are now 47K
    [redundant12v.kicad_pcb, redundant12v.kicad_sch]
2022-10-03 Add Gerber files
    [redundant12v.kicad_pcb]
2022-10-03 Add schematic in PDF format
2022-10-04 Replace premade cable with parts to make a shorter one
2022-10-04 Fix values of R3 and R4 on schematic
    [redundant12v.kicad_pcb, redundant12v.kicad_sch]
2022-11-26 Add PCB photo
2022-12-07 Add crimp connectors to parts list
2023-04-30 Ignore KiCad preferences file
2023-06-28 Upgrade files to KiCad 7
    [drill_template_panel.kicad_pcb, redundant12v.kicad_pcb, redundant12v.kicad_sch]
2023-06-28 Split KiCad projects into subdirectories
    [drill_template_erdn40.kicad_pcb, drill_template_panel.kicad_pcb, redundant12v.kicad_pcb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]
2023-10-21 Fix typos in comments
    [main.asm]

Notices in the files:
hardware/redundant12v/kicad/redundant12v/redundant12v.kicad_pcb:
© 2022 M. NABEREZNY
